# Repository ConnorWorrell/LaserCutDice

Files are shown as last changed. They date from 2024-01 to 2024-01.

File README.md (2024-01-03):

# Laser Dice

This project provides a utility for generating dxf files for tiles with tabs on the edges that mesh with themselves rotated 180 degrees.

These tiles can then be assembled into dice.

This image shows the following: D4, D6, D8, D10, D12, and D20.

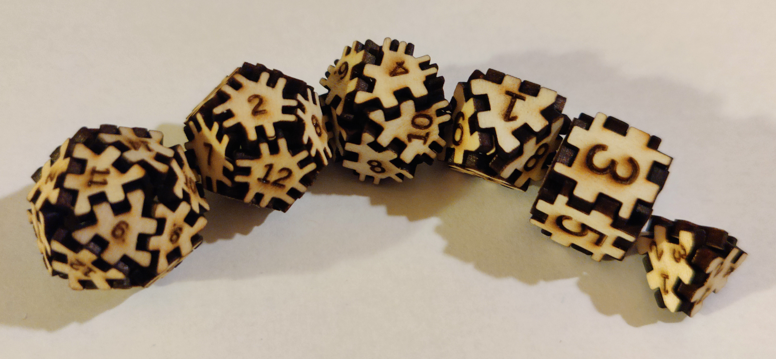
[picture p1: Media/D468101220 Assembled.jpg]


Provided are scrips for automating the export of dxf files for pregenerated dice:
1. `ExportAll.sh` : Runs all other scripts.
2. `ExportD4.sh` : 4 Sided Dice
2. `ExportD6.sh` : 6 Sided Dice
2. `ExportD8.sh` : 8 Sided Dice
2. `ExportD10.sh` : 10 Sided Dice
2. `ExportD12.sh` : 12 Sided Dice
2. `ExportD20.sh` : 20 Sided Dice

The following scad files are provided:
1. `TabTileGenerator.scad` Generates the tiles given parameters.
    1. `LaserRelief`: Tuning parameter to account for laser beam radius.
    2. `TabDepthRelief`: Tuning parameter so tabs are cut to aproximately the same depth as the material is thick.
    3. `TabClearance`: Tuning parameter to adjust tab and slot width.
    4. `BaseThickness`: Thickness of material
    5. `TextThickness`: For STL export
    5. `Sides`: Number of equal sides.
    6. `Inscribed DiameterInput`: Diamter of circle intersecting all corners.
    7. `TabCount`: Tabs per side.
    8. `D10`: Use D10 shape instead of equal sides.
    9. `D4`: Cut 3 characters instead of 1.
        1. `D4Pattern`: Array containing ordered characters to be show counterclockwise.
        2. `D4Offset`: Text offset from center
    10. `Text`: Text to cut into dice.
    11. `TextSizeOverride`: Override default text size.
    12. `Offset`: Translate shape from origin (usefull during import to force multiple tiles not be stacked)
2. `LayoutAll.scad` Generates a single dxf with tiles layed out. Grabs dxf files from directories created in ExportD\*.sh.
    1. `offset`: Spacing between tiles.
    2. `DiceToLayout`: Array containing diles to include.
    3. `XDimmOverride`: force override by n layout. 
    3. `YDimmOverride`: force n by override layout.

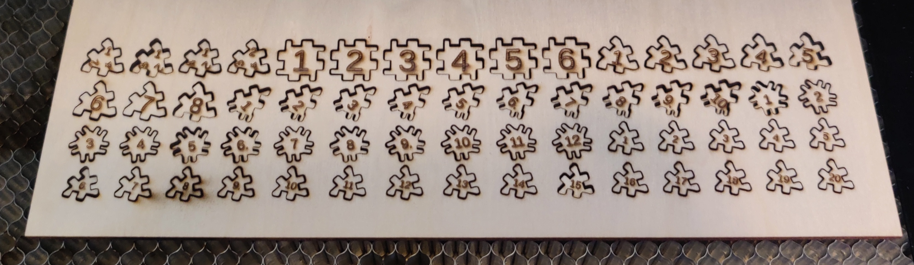
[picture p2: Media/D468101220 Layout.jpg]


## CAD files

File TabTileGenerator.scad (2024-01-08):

LaserRelief=.75; //Aproximate radius of laser beam
TabDepthRelief=.34; //Tuned so tabs are ~the same depth as the thickness
TabClearance = .6; //Tuned so tabs just barely stick together

BaseThickness = 1.5; //For stl export
TextThickness = 1; //For stl export
Sides = 4;
InscribedDiameterInput = 22.62741; //Diameter of circle that inscribes the tile
// 16mm D4:  22.6274
// 16mm D6:  22.6274
// 16mm D8:  22.62405
// 16mm D10:
// 16mm D12: 12.2262 for 1.5mm base thickness the geometry for this needs to be bigger to function
// 16mm D20: 
InscribedDiameter = InscribedDiameterInput;
TabCount = 2; //Minimum 2 tabs
TabDepth = BaseThickness+LaserRelief+TabDepthRelief;

D10=false;
cordsToCatD10=[[0,11.4834],[6.7015,-2.31554],[0,-5.58025],[-6.7015,-2.31554]]*InscribedDiameterInput/22.672741; //D10 shape

D4=false;
D4Pattern = [[1,2,4],[1,3,2],[1,4,3],[2,3,4]];
D4Offset = 4;

//Parameters to generate a "skew dice" variant, modified from origional code by Carlos Luna (carlos.luna@mmaca.cat)
D6Skew=false;
D6Phase=30;
D6Stretch=1;
assert(0 <= D6Stretch);
assert(0 <= D6Phase && D6Phase <= 120);
cordsToCatD6Skew = skewDiceGenerator(phase=D6Phase,stretch=D6Stretch)*InscribedDiameterInput/1.6329875;

Text = "1";
TextSizeOverride=0;
TextRotation = D10==false?(D6Skew==false?-360/(Sides*2)+90:0):0; //Always align text with an edge
TextSize = TextSizeOverride==0?InscribedDiameterInput*.254*(-1/Sides^2.5+1.5-2.5/Sides)*(D10==false?1:.5*InscribedDiameterInput/22.62741):TextSizeOverride;

Offset = 0;

cordsOverride = D10==true ? cordsToCatD10 : (D6Skew==true ? cordsToCatD6Skew : []);

translate([Offset,0,0])difference(){offset(r=LaserRelief,chamfer=false,$fn=30) projection(cut=false)
    //Tile
    linear_extrude(BaseThickness) tile(r=InscribedDiameter/2, order=Sides, tabs=TabCount, tablength=TabDepth, cordsOverride=cordsOverride);
    //Text
    if(D4 == false){
        projection(cut=false)linear_extrude(BaseThickness+TextThickness)rotate([0,0,TextRotation])text(Text, halign="center",valign="center", size=TextSize);
    }
    else{
        //If text is even we do the right handed pattern, if it is odd we do the left handed pattern.
        D4PatternToCut=D4Pattern[ord(Text)-49]; //-48 to convert to int, and -1 to change 1 to 0

        projection(cut=false)linear_extrude(BaseThickness+TextThickness)rotate([0,0,TextRotation])translate([0,D4Offset,0])text(str(D4PatternToCut[0]), halign="center",valign="center", size=TextSize);
        projection(cut=false)linear_extrude(BaseThickness+TextThickness)rotate([0,0,TextRotation+120])translate([0,D4Offset,0])text(str(D4PatternToCut[1]), halign="center",valign="center", size=TextSize);
        projection(cut=false)linear_extrude(BaseThickness+TextThickness)rotate([0,0,TextRotation+120*2])translate([0,3,0])text(str(D4PatternToCut[2]), halign="center",valign="center", size=TextSize);
    }
}

 module tile(order = 4, r=1, tabs=2, tablength=3, cordsOverride=[]){

     
     angles=[ for (i = [0:order-1]) i*(360/order) ];
     cordsToCat = cordsOverride==[] ? [ for (th=angles) [r*cos(th), r*sin(th)] ] : cordsOverride;

         
     difference(){
         polygon(cordsToCat);
             
         //For each side
         for(j=[1:1:len(cordsToCat)]){
             firstPoint=cordsToCat[j-1];
             secondPoint=cordsToCat[j==len(cordsToCat)?0:j];
             parrSide = firstPoint-secondPoint;
             normSide=parrSide/norm(parrSide);
             
             parrVect=-parrSide/(tabs);
             perpVect=[normSide[1],-normSide[0]]*tablength;
             
             //Generate tabs to remove
             for(tab=[0:1:tabs-1]){
                polygon([firstPoint+parrVect*tab-perpVect-(tab==0&&!D10?parrVect:[0,0])+TabClearance*normSide, firstPoint+parrVect*tab+perpVect-(tab==0&&!D10?parrVect:[0,0])+TabClearance*normSide, firstPoint+parrVect*tab+perpVect+parrVect/2-TabClearance*normSide, 
        firstPoint+parrVect*tab+parrVect/2-perpVect-TabClearance*normSide]);
             }
        }
    }
 }
 
 function addl(list, c = 0) = 
 c < len(list) - 1 ? 
 list[c] + addl(list, c + 1) 
 :
 list[c];
 
 function skewDiceGenerator(phase=30, stretch=1, size=16) = 
    // Constants:
    let (K = sqrt(3))
    let (R = size*K/2)
    let (C = cos(phase))
    let (S = sin(phase))
    
    // Coordinates of the main equatorial vertex: [X,0,Z]
    let (L = (C-1)*(S-K/2) - S*(C+1/2))  // <= Geometric Voodoo
    let (Z = L/(L-K))                    // <= Geometric Voodoo
    let (X = sqrt(1-Z*Z))
     
    // Vertical scaling factor:
    let (v_scale = (stretch == 0) ? (X/((1-Z)*sqrt(2))) : stretch)
    
    // Derivation of all other vertices from the vertex: [X,0,Z]
    let(initial = [[0,0,0],[-X/2,K*X/2,(Z-1)*v_scale],[C*X,S*X,-(Z+1)*v_scale],[X,0,(Z-1)*v_scale]])
 
    //Begin of adjusting to work for this program
    //Rotate around the x and y axis to get all points onto the XY plane
    let(yRotation = atan(initial[3][2]/initial[3][0]))
    let(yRotMatrix = [[cos(yRotation),0,sin(yRotation)],[0,1,0],[-sin(yRotation),0,cos(yRotation)]])
    //initial;
    let(yRotated = [ for (i = initial) yRotMatrix*i])
    
    let(xRotation = -atan(yRotated[1][2]/yRotated[1][1]))
    let(xRotMatrix = [[1,0,0],[0,cos(xRotation),-sin(xRotation)],[0,sin(xRotation),cos(xRotation)]])
    
    let(xRotated = [for (i = yRotated) xRotMatrix*i])
        
    //Center the cube
    let(tile=[for (i = xRotated) [i[0],i[1]]])
    let(xAvg= addl([for (i=tile) i[0]])/4)
    let(yAvg= addl([for (i=tile) i[1]])/4)
    [for (i=tile) [i[0]-xAvg,i[1]-yAvg]];

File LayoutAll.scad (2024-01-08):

offset = 20;

DiceToLayout=[
[4,"",""],
[6,"",""],
[8,"",""],
[10,"",""],
[12,"",""],
[20,"",""],
[6,"Skew","NSNR"],
[6,"Skew","NSR"],
[6,"Skew","SNR"]];
XDimmOverride = 0;
YDimmOverride = 0;

function addl(list, c = 0) = 
 c < len(list) - 1 ? 
 list[c] + addl(list, c + 1) 
 :
 list[c];

TotalDice=addl([for (i=DiceToLayout) i[0]]);
assert(XDimmOverride * YDimmOverride == 0 || !(XDimmOverride * YDimmOverride < TotalDice), "Too few layout locations, increase XDimm or YDimm");

MaxOverrideDimension = max([XDimmOverride, YDimmOverride]);

XDimm = XDimmOverride == 0 ? (MaxOverrideDimension != 0 ? round(TotalDice/MaxOverrideDimension) : round(sqrt(TotalDice))) : XDimmOverride;
YDimm = YDimmOverride == 0 ? round(TotalDice/XDimm) : YDimmOverride;

DiceValue = [for (i=DiceToLayout) each [for (p=[1:i[0]]) ((p == 6 || p == 9) && i[0] >= 9 ? str(str(p),".") : p)]];
DiceSides = [for (i=DiceToLayout) each [for (p=[1:i[0]]) i[0]]];
DiceFolderPrefix = [for (i=DiceToLayout) each [for (p=[1:i[0]]) i[1]]];
DiceTypePrefix = [for (i=DiceToLayout) each [for (p=[1:i[0]]) i[2]]];

echo(DiceValue)

for (xPos=[0:XDimm-1],yPos=[0:YDimm-1]){
    absPos = xPos*YDimm+yPos;
    
    Value = str(DiceValue[absPos]);
    Sides = str(DiceSides[absPos]);
    FolderPrefix = str(DiceFolderPrefix[absPos]);
    TypePrefix = str(DiceTypePrefix[absPos]);
    
    DiceLocation = FolderPrefix == "" && TypePrefix == ""
        ? str("D", Sides,"_Export/D",Sides,"-",Value,".dxf")
        : str("D", Sides,FolderPrefix,"_Export/",TypePrefix,"/D",Sides,FolderPrefix,TypePrefix,"-",Value,".dxf");
    
    translate([xPos*offset,yPos*offset])rotate([0,0,45])import(DiceLocation);
    echo(DiceLocation, Value, Sides, absPos, xPos, yPos);
}

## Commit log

2024-01-03 Corrected D4 text layout, now shows 3 smaller number per side
    [TabTileGenerator.scad]
2024-01-03 Utility for laying out multiple tiles and exporting as dxf because lightburn ignores dxf origin and will stack all tiles on top of each other making the layout very time consuming. Not yet fixed in l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
    [LayoutAll.scad]
2024-01-03 Corrected the 3 side of D4 showing a 2
    [TabTileGenerator.scad]
2024-01-08 Skew tile option/generators added
    [LayoutAll.scad, TabTileGenerator.scad]
